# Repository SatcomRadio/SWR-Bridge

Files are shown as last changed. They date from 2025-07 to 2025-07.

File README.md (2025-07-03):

# SWR measurement board

This repo consists of a board for measuring SWR. It works up to 500mhz and 1kW of power in HF.  
The pickup lines are 20 db attenuated.  

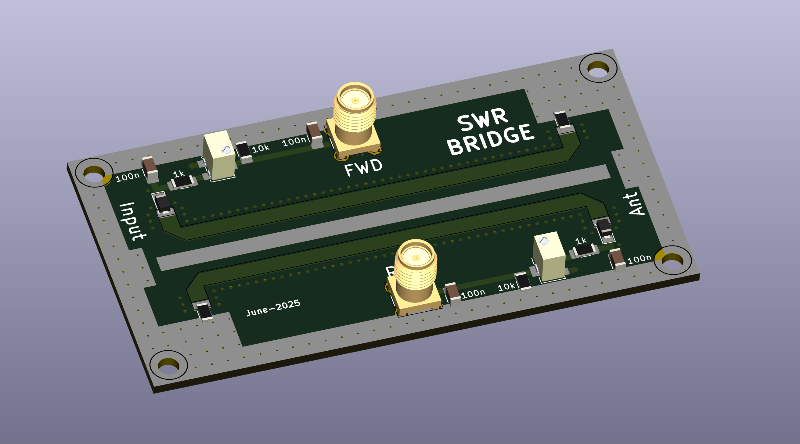
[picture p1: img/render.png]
render


You can connect it to an arduino and measure the FWD and reflected power.

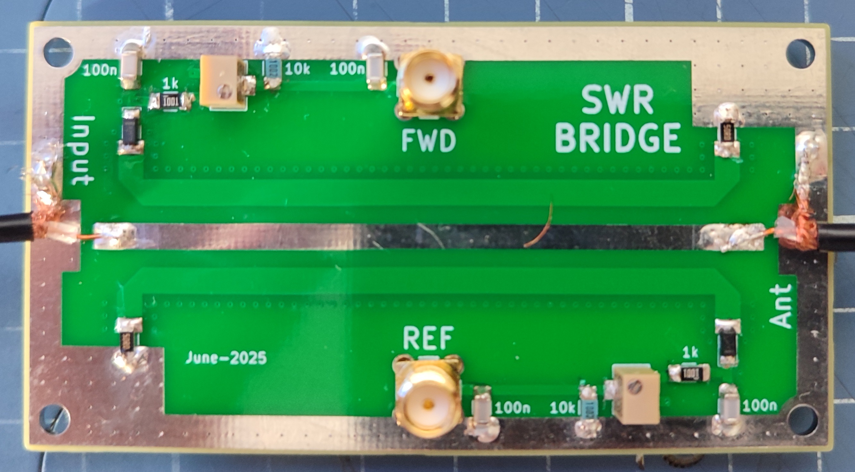
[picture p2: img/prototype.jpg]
prototype


The potentiometers allow to calibrate the maximum power seen at the FWD and REF   
ports so you can get more resolution at higher or lower RF power levels.

*Keep the 2 potentiometers at the same resistance value*

------------------------

## BOM:

```
- PCB that you can order ar jlcpcb or somewhere else.
- 2x SMD 3224W 10k potentiometers. You can use 5k if you plan to measure low power. (https://aliexpress.com/item/1005009122898646.html)
- 2x 1206 50 ohm resistor (https://aliexpress.com/item/1005008118472536.html)
	alternatively, you can use 4x 100 ohm 1206 resistors.
- 4x 1206 100nF 200v NPO Capacitor (https://aliexpress.com/item/1005007149614327.html)
- 2x 1206 1k ohm resistor
- 2x 1206 10k ohm resistor
- 2x MMSD701T1G Diode (https://aliexpress.com/item/1005008691014348.html)
- 2x SMA SMA-KE 13.5MM connectors (https://aliexpress.com/item/1005007424915378.html)
```

------------------------

## Reading the SWR in a Arduino

**Important, this section is currently work in progress and the code might change**

You can order an arduino UNO board along with a [LCD shield](https://es.aliexpress.com/item/32475515474.html) to read the millivolts.

Before doing so, push the maximum power of your radio trough the SWR board and to a dummy load.  
While doing so, adjust the potentiometer with a multimeter so the volts in the FWD line are lower than 4.5v  
as that will avoid burning the arduino ADC.  
  
You can check the sample code for the arduino in the Arduino folder of the repo.  

------------------------

## Ordering the PCB:

Download the Gerber file from this repo and order it a jlcpcb with the default options.  
The only option I've changed is to remove the manufacture code mark

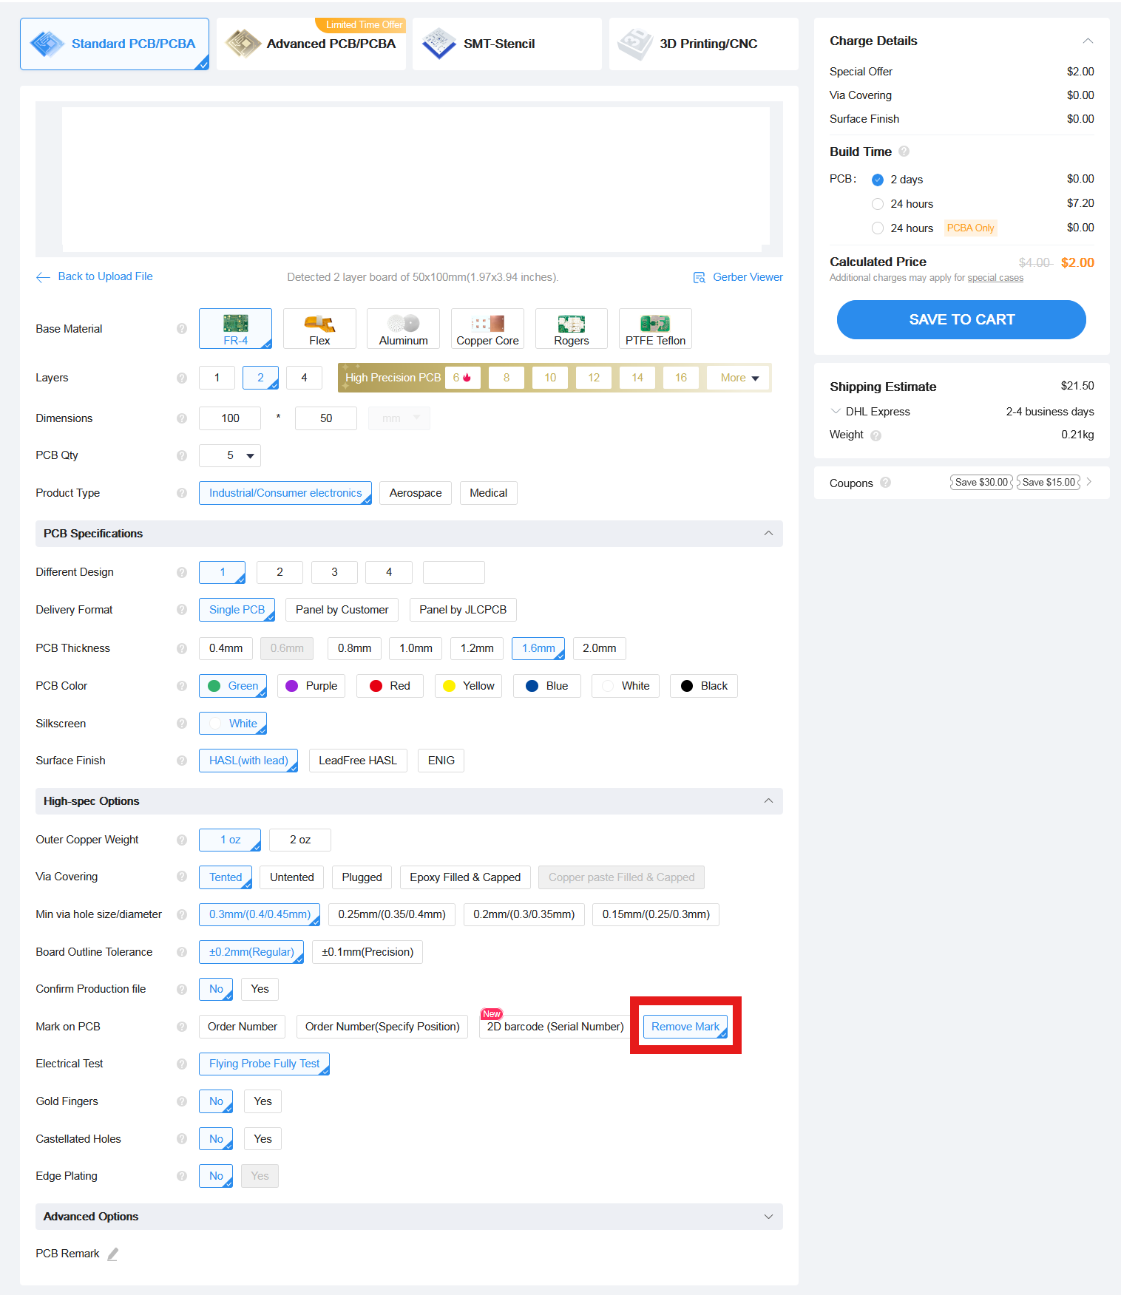
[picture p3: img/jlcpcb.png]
jlcpcb


#### Please make sure to visit the [satcom radio website](https://satcomradio.github.io/) for more information

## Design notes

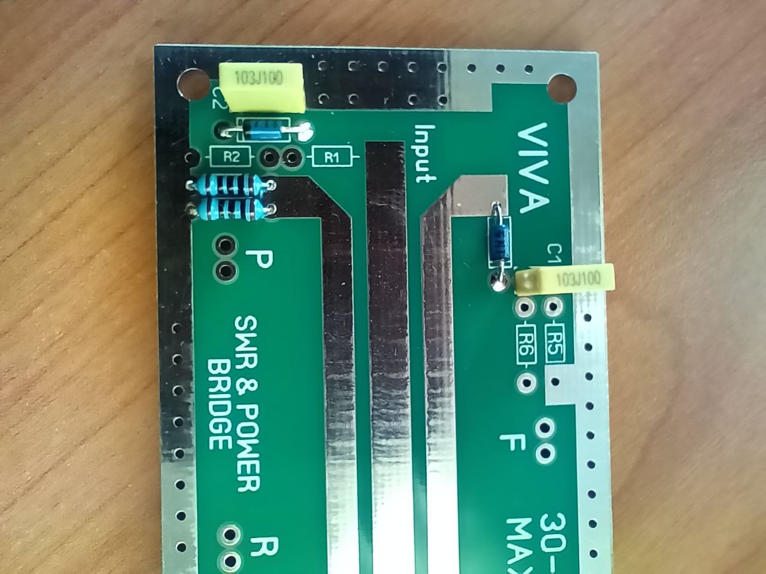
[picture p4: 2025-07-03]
img/Original/det3.jpg

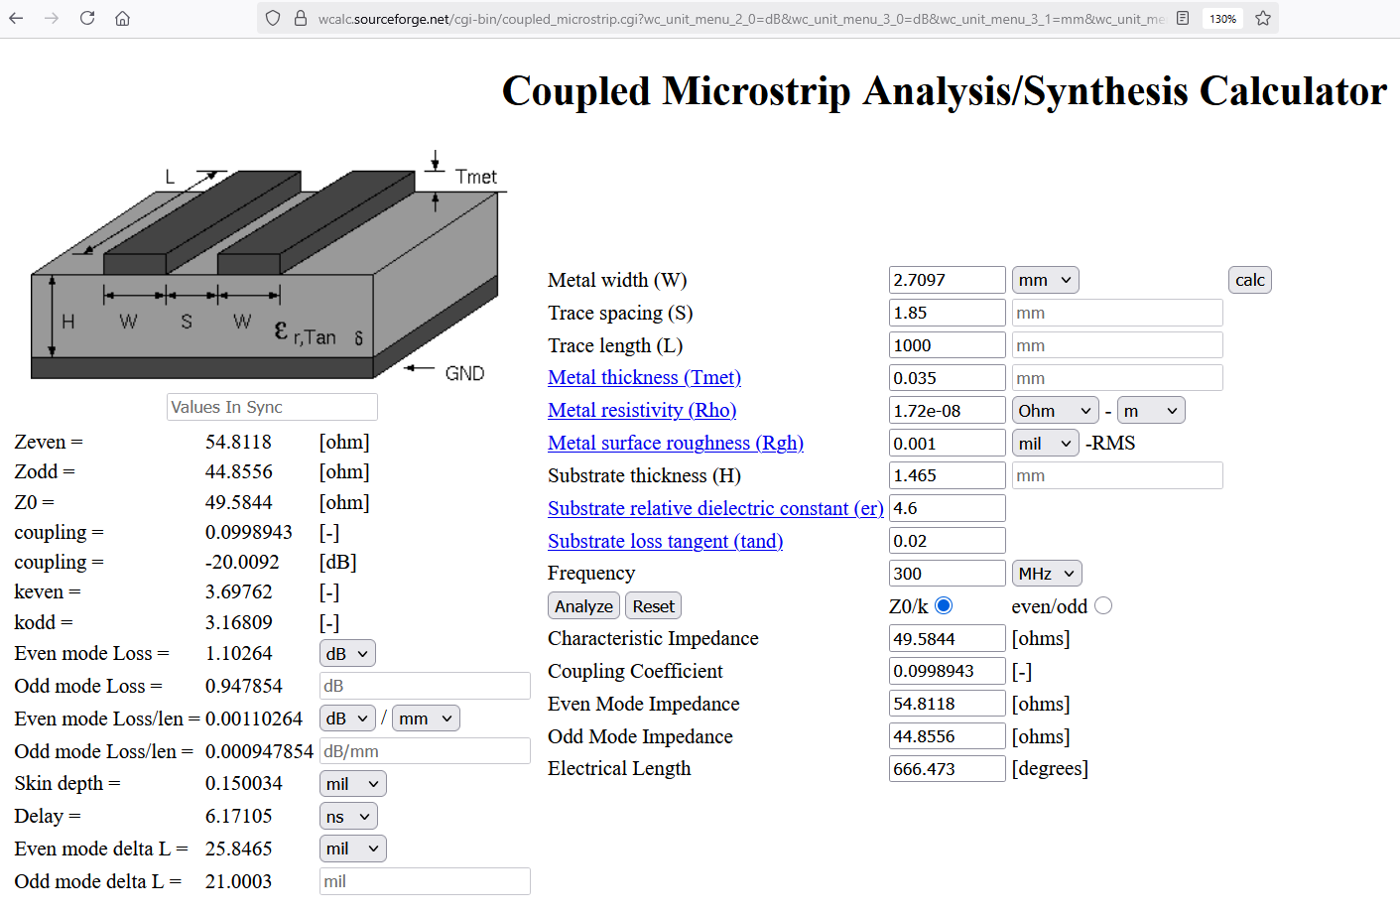
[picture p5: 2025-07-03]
img/Coupling Calc.png

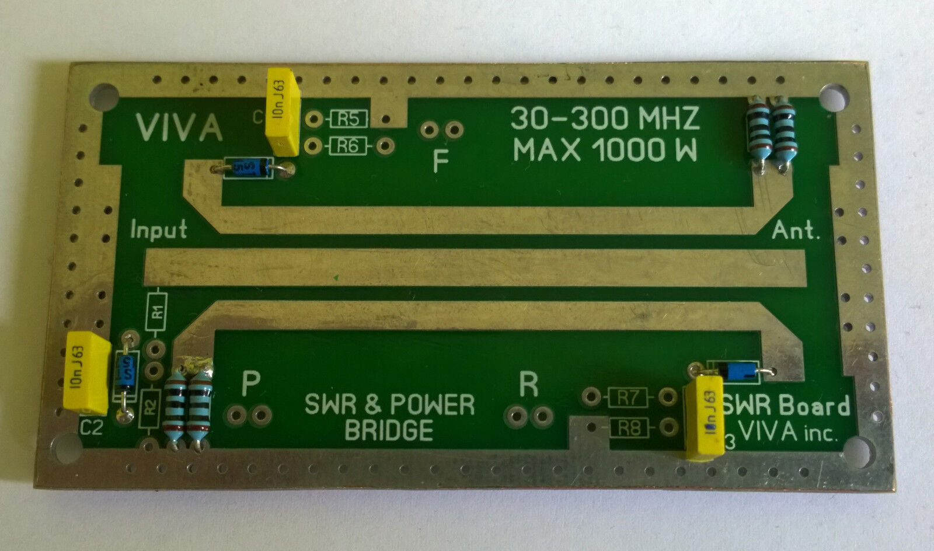
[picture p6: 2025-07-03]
img/Original/board2.jpg

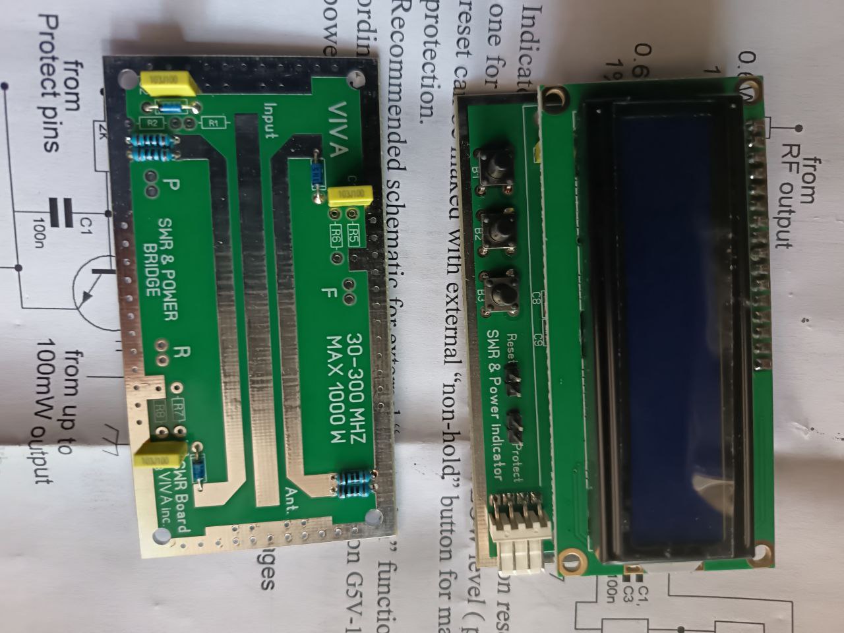
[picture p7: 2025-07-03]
img/Original/board.jpg

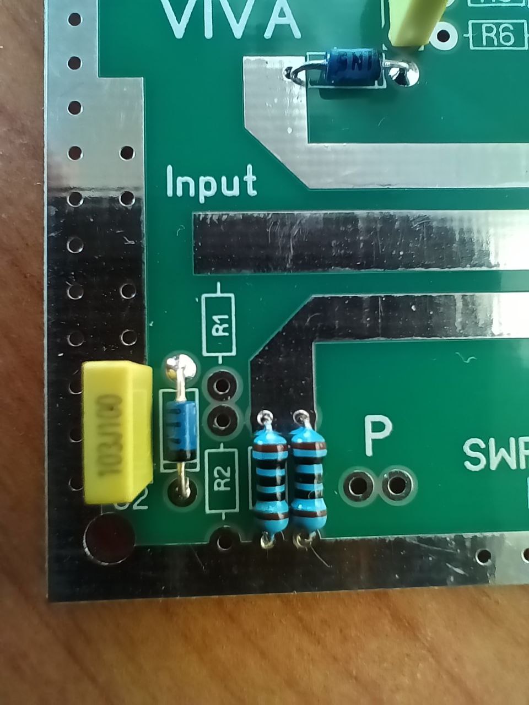
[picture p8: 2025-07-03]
img/Original/det2.jpg

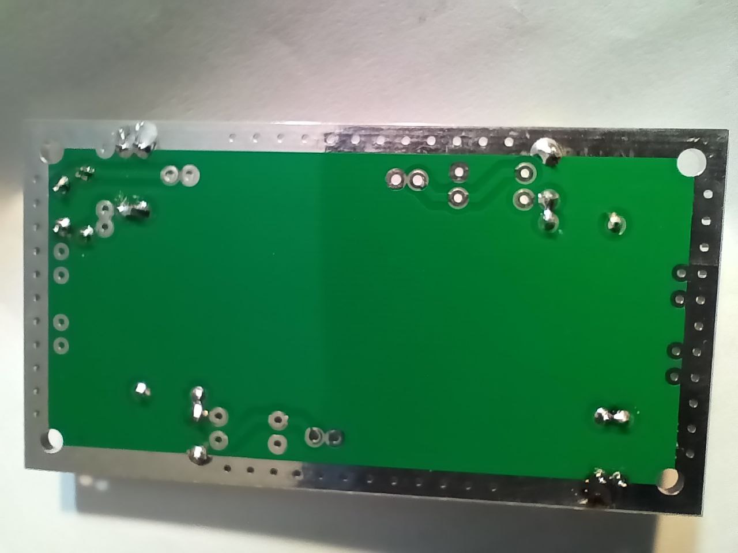
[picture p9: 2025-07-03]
img/Original/back.jpg

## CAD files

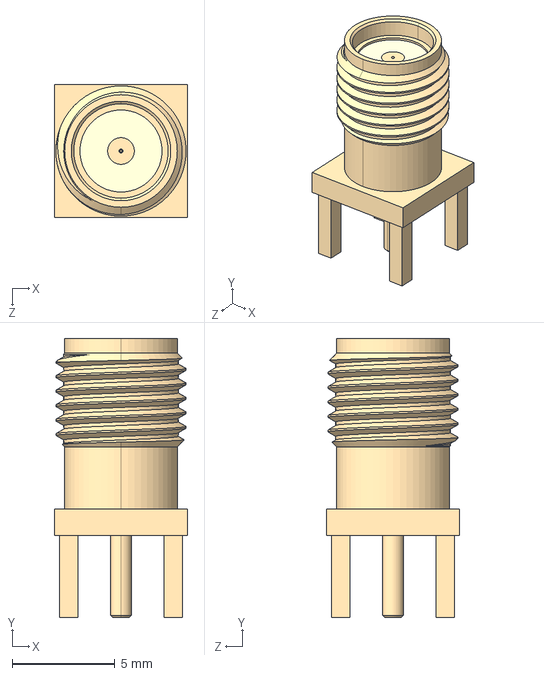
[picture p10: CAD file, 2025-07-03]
Kicad/3D/SMA_CONNECTOR.step
6.50 x 13.6 x 6.50 mm

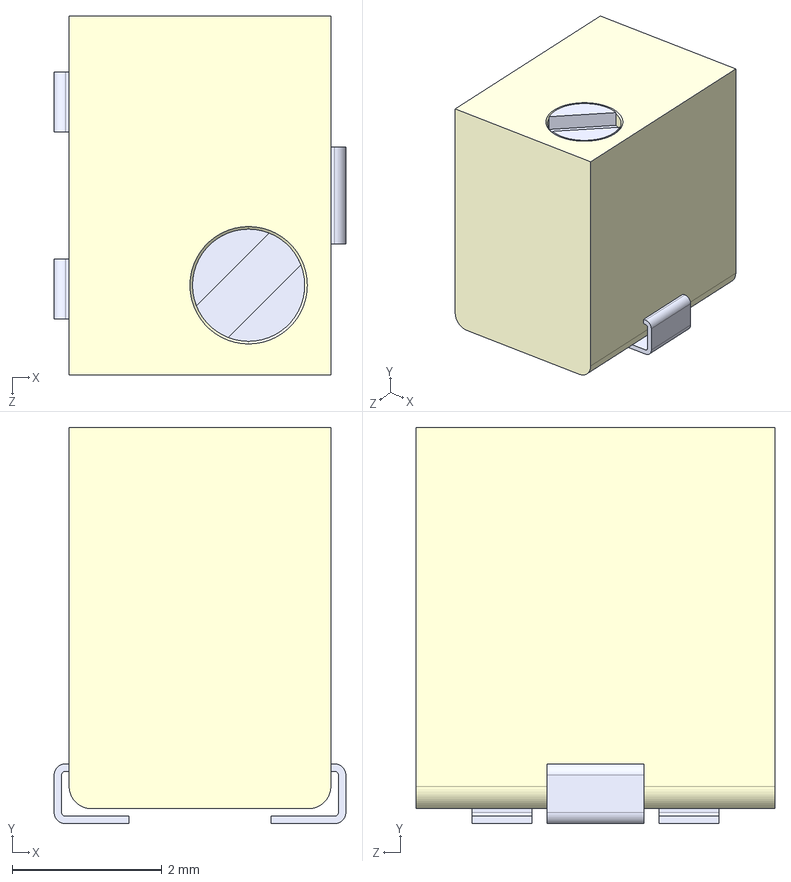
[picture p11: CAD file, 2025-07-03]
Kicad/3D/Pot.STEP
3.90 x 5.30 x 4.80 mm

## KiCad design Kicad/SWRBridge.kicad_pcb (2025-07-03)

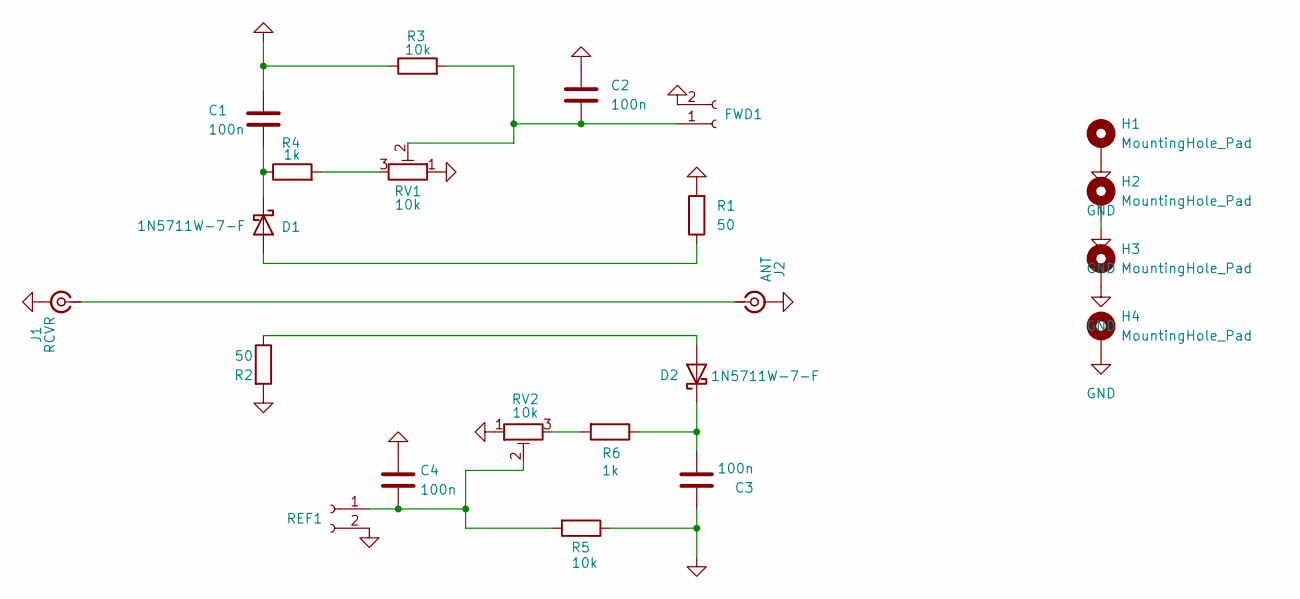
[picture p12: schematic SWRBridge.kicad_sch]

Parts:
C1, C2, C3, C4: 100n; C_1206_3216Metric_Pad1.33x1.80mm_HandSolder
D1, D2: 1N5711W-7-F; Nexperia_CFP3_SOD-123W_EXPANDED
FWD1: Conn_01x02_Socket; SMA_Conn
H1, H2, H3, H4: MountingHole_Pad; MountingHole_3.2mm_M3_DIN965_Pad
J1: RCVR; RfConnector_S
J2: ANT; RfConnector_S
R1, R2: 50; R_1206_3216Metric_Pad1.30x1.75mm_HandSolder
R3, R5: 10k; R_1206_3216Metric_Pad1.30x1.75mm_HandSolder
R4, R6: 1k; R_1206_3216Metric_Pad1.30x1.75mm_HandSolder
REF1: Conn_01x02_Socket; SMA_Conn
RV1, RV2: 10k; Potentiometer_Bourns_3224W_Vertical_EXPANDED

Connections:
GND: C1.1, C2.1, C3.1, C4.1, FWD1.2, H1.1, H2.1, H3.1, H4.1, J1.2 (Ext), J2.2 (Ext), R1.2, R2.2, R3.1, R5.1, REF1.2, RV1.1, RV2.1
unnamed: D1.2 (A), R1.1
unnamed: C1.2, D1.1 (K), R4.1
unnamed: D2.2 (A), R2.1
unnamed: C3.2, D2.1 (K), R6.1
unnamed: C2.2, FWD1.1, R3.2, RV1.2
unnamed: J1.1 (In), J2.1 (In)
unnamed: R4.2, RV1.3
unnamed: R6.2, RV2.3
unnamed: C4.2, R5.2, REF1.1, RV2.2

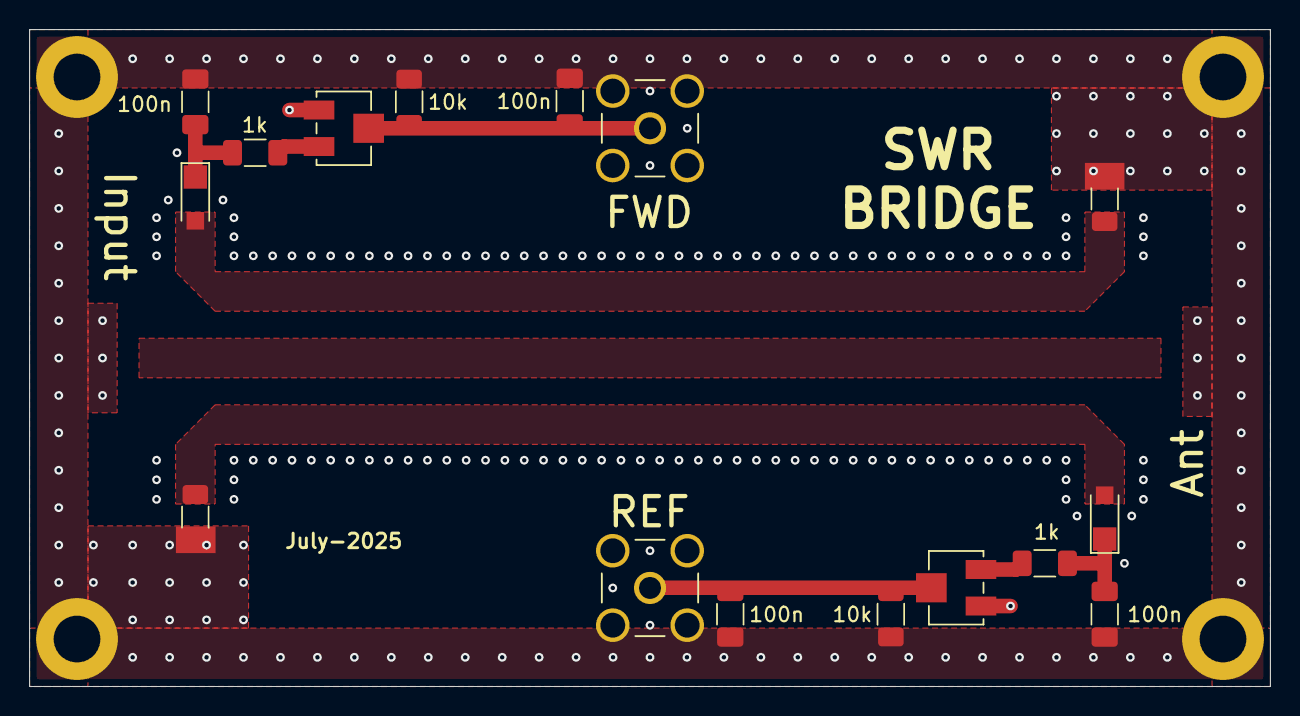
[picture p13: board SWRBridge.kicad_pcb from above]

Board: 2 copper layers, 85.0 x 45.0 mm, 20 parts (0 on the bottom side), 9 nets.

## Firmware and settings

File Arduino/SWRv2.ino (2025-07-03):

#include <LiquidCrystal.h>
#include <math.h>


// ─── Set to 1 temporarily to display detector voltage for calibration ───
#define CAL_MODE 0

// === Hardware pin assignments ===
LiquidCrystal lcd(8, 9, 4, 5, 6, 7);
const uint8_t PIN_FWD = A5;  // Forward detector
const uint8_t PIN_REF = A4;  // Reflected detector

// === Fixed parameters for 70 cm band ===
const unsigned int DIODE_mV = 410;   // Detector diode drop (mV)
const float POW_MW  = 7.2;   // *** Replace after calibration ***
const unsigned long FW_MW  = 1363;   // *** Replace after calibration ***
const unsigned long REF_MW  = 507;   // *** Replace after calibration ***

unsigned long POW_CAL  = pow(FW_MW, 2)/POW_MW/1000;
// PowCal= (VoltFWD²/Power) / 1000  (where power is expressed in Watt)

// Timing
const unsigned long REFRESH_INTERVAL = 200;  // ms
unsigned long nextRefresh = 0;

// ────────────────────────────  S E T U P  ───────────────────────────────
void setup() {
  lcd.begin(16, 2);
  lcd.clear();
  lcd.setCursor(0, 0); lcd.print("70 cm Pwr/SWR");
  lcd.setCursor(0, 1); lcd.print("Meter Ready   ");
  delay(2000);
  lcd.clear();
}

// ────────────────────────────  L O O P  ────────────────────────────────
void loop() {
  if (millis() >= nextRefresh) {
    nextRefresh = millis() + REFRESH_INTERVAL;
#if CAL_MODE
    showCalibrationVoltage();
#else
    refreshDisplay();
#endif
  }
}

// ======================================================================
//                     C A L I B R A T I O N   M O D E
// ======================================================================
#if CAL_MODE
void showCalibrationVoltage() {
  float voltFwd = analogRead(PIN_FWD);
  voltFwd = map(voltFwd, 0, 1023, 0, 5000) + DIODE_mV;  // mV
  float voltRef = analogRead(PIN_REF);
  voltRef = map(voltRef, 0, 1023, 0, 5000) + DIODE_mV;  // mV

  lcd.setCursor(0, 0);
  lcd.print("VoltFWD=");
  lcd.print((unsigned int)voltFwd);
  lcd.print("mV   ");
  lcd.setCursor(0, 1);  
  lcd.print("VoltREF=");
  lcd.print((unsigned int)voltRef);
  lcd.print("mV   ");
}
#endif

// ======================================================================
//                 R E G U L A R   M E T E R   D I S P L A Y
// ======================================================================
void refreshDisplay() {
  // ── Read detector voltages ───────────────────────────────────────────
  float voltFwd = analogRead(PIN_FWD);
  float voltRef = analogRead(PIN_REF);

  voltFwd = map(voltFwd, 0, 1023, 0, 5000) + DIODE_mV;  // mV
  voltRef = map(voltRef, 0, 1023, 0, 5000) + DIODE_mV;  // mV

  // ── Power calculation (W) ────────────────────────────────────────────
  double pwrW = pow(voltFwd, 2) / POW_CAL / 1000.0;

  // ── SWR calculation ──────────────────────────────────────────────────
  double swr = -1.0;  // negative ⇒ no meaningful reading
  if (voltFwd > (DIODE_mV + 2)) {
    const float vRatio = voltRef / voltFwd;
    if (vRatio < 1.0) swr = (1 + vRatio) / (1 - vRatio);
  }

  // ── LCD line 0 : Power ───────────────────────────────────────────────
  lcd.setCursor(0, 0);
  lcd.print("Pwr     ");  // clear field
  lcd.setCursor(4, 0);

  if (pwrW < 1.0) {
    const int mW = (int)(pwrW * 1000 + 0.5);
    lcd.print(mW); lcd.print("mW   ");
  } else {
    const int whole = (int)pwrW;
    const int tenth = (int)(pwrW * 10) % 10;
    lcd.print(whole); lcd.print('.'); lcd.print(tenth); lcd.print("W   ");
  }

  // ── LCD line 1 : SWR ────────────────────────────────────────────────
  lcd.setCursor(0, 1);
  lcd.print("SWR ");

  if (swr < 0) {
    lcd.print("-.-- 70cm");
  } else {
    const int swr10 = (int)(swr * 10 + 0.5);
    const int swrW  = swr10 / 10;
    const int swrD  = swr10 % 10;
    if (swrW < 10) lcd.print(' ');  // align
    lcd.print(swrW); lcd.print('.'); lcd.print(swrD); lcd.print(" 70cm");
  }
}
